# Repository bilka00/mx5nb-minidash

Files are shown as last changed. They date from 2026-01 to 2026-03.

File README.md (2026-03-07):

# Mazda MX-5 NB minidash
  Mini gauge display for Mazda MX-5 NB — oil pressure, temps, ECU data (Invent Labs, ME442). Replaces stock oil pressure gauge (or other 42mm gauge)
  Waveshare RP2350 + 1.43" AMOLED - https://www.waveshare.com/product/rp2350-touch-amoled-1.43.htm
  Preview:
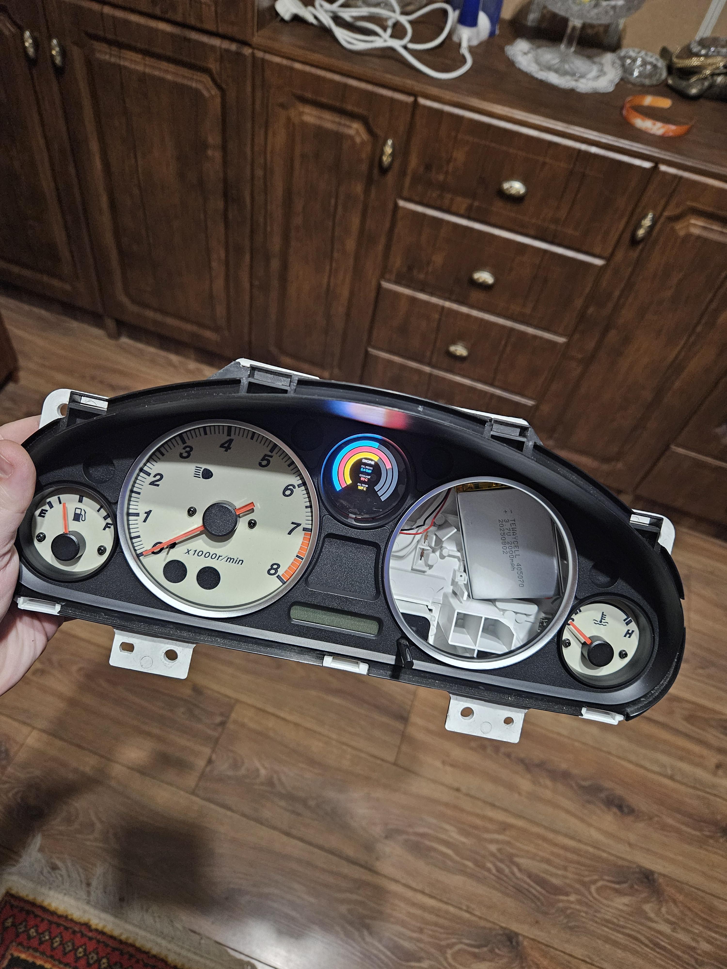
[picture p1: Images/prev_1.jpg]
First demo preview
  
## PCB
  Gerbers for pcb
  I received the boards from the factory and have already conducted the first tests. 
RS232 - works stably. The DC-DC ratings in the circuit are selected from those I have, you can choose better (resistors R7 R8).
  CAN bus works too!
  I haven't tested the ADC yet, I'm waiting for the components.
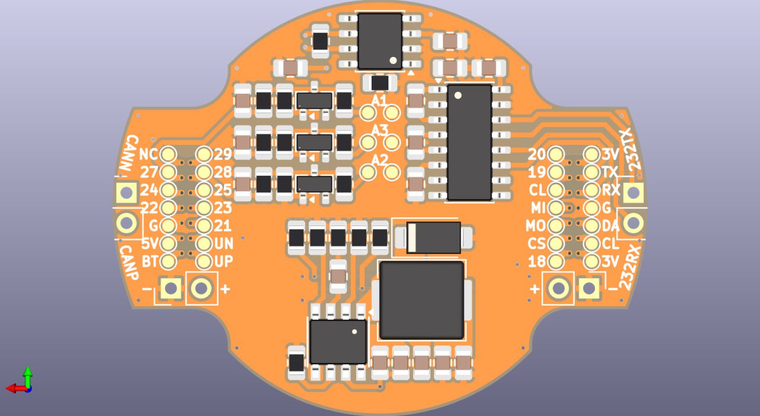
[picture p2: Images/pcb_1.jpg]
PCB_1
  
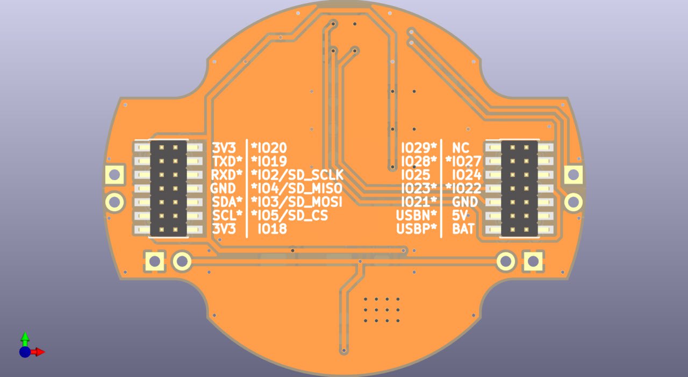
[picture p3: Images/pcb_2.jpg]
PCB_2
  
## Source 
  There are two projects there. One is an emulator, it can emulate both Invent and CAN ME442 (but that's not accurate, Claude). The second is the dashboard firmware itself, see config.h
## 3D Model
  3D models designed for 3D printing to mount the display to replace the factory gauge
## Demo
  Firmware source code for Demo application
## Invent Labs EMS (While this integration is not implemented)
  Firmware source code and scematic for EMS BUS intergate 
  
  Invent Labs EMS Bus is Inverted 12V UART (NOT RS232!!!, hotfix: 2k resistor - RS232 RX and VIN), speed 19200bps
  
  New board in progress. Let's abandon max2323 and make an inverter + logic level convertor on n-mos
  
## ME442 (While this integration is not implemented)
  Firmware source code and scematic for ME442 CAN intergate 
  
  ME442 CAN is CAN2.0b, variable speed, Command DB
## Images
  Image for readme

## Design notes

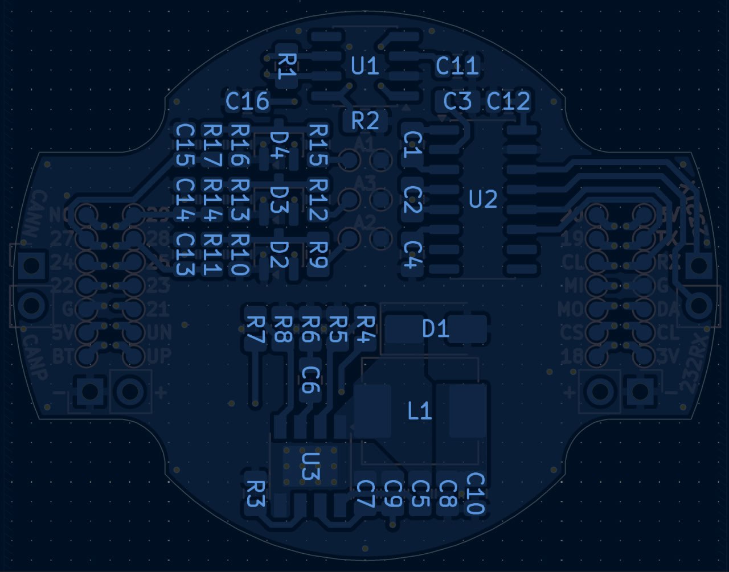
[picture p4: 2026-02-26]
PCB/footprint.jpg

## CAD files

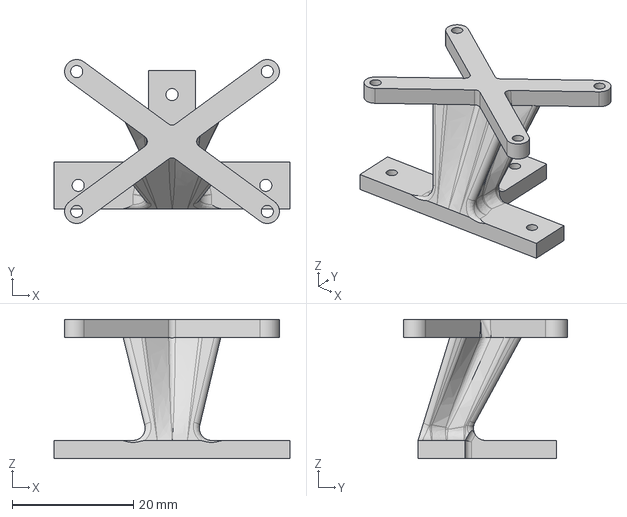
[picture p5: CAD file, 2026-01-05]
3D Model/MiataNB_DASH_OIL_REPLACE.step
39.0 x 27.1 x 23.0 mm

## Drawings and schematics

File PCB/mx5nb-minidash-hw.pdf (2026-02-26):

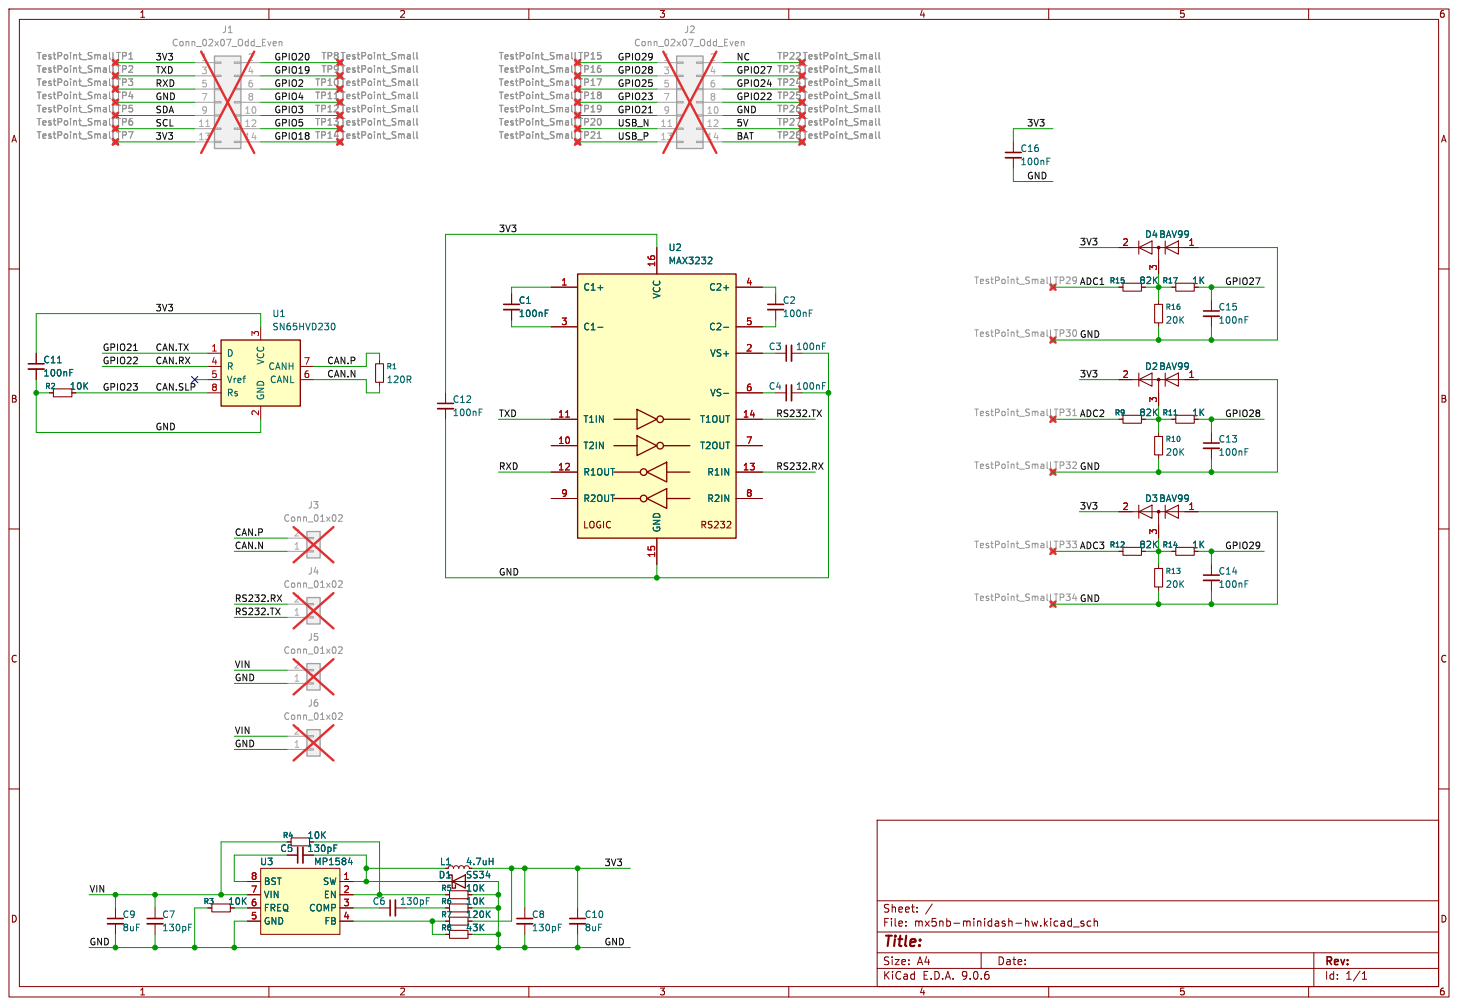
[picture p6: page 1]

2 CANH 7 CANL 6 U1SN65HVD230 RS232.RX GND GND

Id: 1/1 Title: File: mx5nb-minidash-hw.kicad_sch Sheet: /

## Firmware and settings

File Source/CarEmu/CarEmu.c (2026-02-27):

/*
 * Invent EMS Protocol TX Emulator
 * RP2040 (Pico SDK) — UART1 (GP4=TX, GP5=RX)
 *
 * Generates TInfoPacket with rotating slow packets
 * for testing the parser/receiver side.
 *
 * USB CDC serial used for debug/commands (printf).
 */

#include <stdio.h>
#include <string.h>
#include <stdlib.h>
#include <math.h>
#include <stdbool.h>

#include "pico/stdlib.h"
#include "pico/stdio_usb.h"
#include "hardware/uart.h"
#include "hardware/irq.h"
#include "hardware/clocks.h"
#include "can2040.h"

// ============================================================
// Type aliases
// ============================================================
typedef uint8_t  uint8;
typedef int8_t   int8;
typedef uint16_t uint16;
typedef int16_t  int16;

// ============================================================
// Protocol constants
// ============================================================
#define PROTOCOL_VERSION    0x54
#define SLOW_PACKET_SIZE    11
#define SLOW_PACKETS_COUNT  4
#define VERY_SLOW_PACKETS_COUNT 6
#define TOTAL_SLOW_PACKETS  (SLOW_PACKETS_COUNT + VERY_SLOW_PACKETS_COUNT) // 10

// Header: 0x55 0x00 0xAA 0x00 <version>
static const uint8_t HEADER[] = { 0x55, 0x00, 0xAA, 0x00, PROTOCOL_VERSION };
#define HEADER_SIZE 5

// UART1 pins & baud
#define UART_ID      uart1
#define UART_TX_PIN  4
#define UART_RX_PIN  5
#define UART_BAUD    19200

// CAN bus (PIO0, SN65HVD230 transceiver)
#define CAN_PIO_NUM    0
#define CAN_BITRATE    500000
#define CAN_GPIO_TX    21
#define CAN_GPIO_RX    22

// Packet send interval (ms)
#define TX_INTERVAL_MS 20  // ~50 Hz main packet rate

// ============================================================
// Packed structs (mirroring packet_info.h)
// ============================================================
#pragma pack(push, 1)

// --- Flag unions ---

typedef union {
    uint8 All;
    struct {
        uint8 DPKV     : 1,
              DF       : 1,
              DBW      : 1,
              DAD      : 1,
              DNO      : 1,
              CLT      : 1,
              OILP     : 1,
              FUELP    : 1;
    };
} TFlagMajor;

typedef union {
    uint8 All;
    struct {
        uint8 Lambda : 1,
              IAT    : 1,
              FuelT  : 1,
              OilT   : 1,
              VVT    : 1,
              EGR    : 1;
    };
} TFlagMinor;

typedef union {
    uint8 All;
    struct {
        uint8 TableSwitch      : 1,
              InjTimeLimit     : 1,
              Marker           : 1,
              AfterStartEnrich : 1,
              PhasedMode       : 1,
              WritePending     : 1,
              Methanol         : 1,
              IdleCutoff       : 1;
    };
} TFlagNotify;

typedef union {
    uint8 All;
    struct {
        uint8 Launch    : 1,
              FlatShift : 1,
              AntiLag   : 1;
    };
} TFlagNotify2;

typedef union {
    uint8 All;
    struct {
        uint8 Rpm       : 1,
              Overboost : 1,
              Lambda    : 1,
              InjDuty   : 1,
              Clt       : 1,
              Egt       : 1,
              OilT      : 1;
    };
} TFlagProtection;

typedef union {
    uint8 All;
    struct {
        uint8 PartLock  : 1,
              FullLock  : 1,
              Shifting  : 1,
              Retard    : 1,
              __free    : 1,
              Selector  : 3;
    };
} TATState;

// --- Slow packet structs (all padded to SLOW_PACKET_SIZE = 11 bytes) ---

typedef struct {
    int8   CorrAngle;
    uint8  LambdaTarget;
    int8   LambdaCorrFast;
    int8   LambdaCorrSlow;
    uint16 FuelPKpa;
    uint8  DwellTime;
    uint8  Voltage;
    int8   GearNo;
    uint8  DbwCommandedPos;
    uint8  Lambda2;
} TInfoPacketSlow0;

typedef struct {
    TFlagMajor      FlagMajor;
    TFlagMinor      FlagMinor;
    TFlagNotify     FlagNotify;
    TFlagNotify2    FlagNotify2;
    TFlagProtection FlagProtection;
    uint8  IdlePos;
    uint16 Airflow;
    uint8  BoostDuty;
    uint8  BoostTarget;
    uint8  _free;
} TInfoPacketSlow1;

typedef struct {
    uint8  EgrCurrentPos;
    uint8  EgrTargetPos;
    uint8  InjDutyCycle;
    int16  InjLagTime;
    int8   InjEndAngle4;
    uint8  FuelPressureCoef;
    int8   AirChargeT;
    int8   InjAirChargeCorr;
    uint8  Speed2;
    uint8  BackPKpa;
} TInfoPacketSlow2;

typedef struct {
    int16  IgnAccelCorrDelta;
    int8   Vvt1CurrAngle;
    int8   Vvt1TargetAngle;
    int8   Vvt2CurrAngle;
    int8   Vvt2TargetAngle;
    int8   Vvt1bCurrAngle;
    int8   Vvt2bCurrAngle;
    uint8  TcsCorr;
    uint8  Pwm3DTarget;
    uint8  Pwm3DCurr;
} TInfoPacketSlow3;

typedef struct {
    uint16 TripFuel;
    uint16 TripPath;
    uint16 CurrFuelCons;
    uint16 TripFuelCons;
    uint8  FuelComposition;
    uint8  free2;
    uint8  _free;
} TInfoPacketSlow4;

typedef struct {
    uint8  AdcTps;
    uint8  AdcCt;
    uint8  AdcIat;
    uint8  DbwAdc1;
    uint8  DbwAdc2;
    uint8  AdcMap;
    uint8  AdcLambda;
    uint8  SlotNo;
    uint8  SlotLatency;
    uint8  SlotTime;
    uint8  _free;
} TInfoPacketSlow5;

typedef struct {
    uint8  AdcAn1;
    uint8  AdcAn2;
    uint8  AdcAn3;
    uint8  AdcAn4;
    uint8  AdcAn5;
    uint8  AdcAn6;
    uint8  AdcAn7;
    uint8  AdcAn8;
    uint8  AdcAn9;
    uint8  AdcAn10;
    uint8  _free;
} TInfoPacketSlow6;

typedef struct {
    uint8  InputState;
    uint16 OutputState;
    uint8  DbwDriverStatus;
    uint8  DbwSystemStatus;
    uint8  GasState;
    int8   ATTemp;
    uint8  ATState;
    uint8  FuelLevel;
    uint8  padding4;
    uint8  _free;
} TInfoPacketSlow7;

typedef struct {
    int8   Clt;
    int8   Iat;
    uint8  OilT;
    int8   FuelT;
    uint8  _free;
    uint16 Egt1;
    uint16 Egt2;
    uint8  OilP;
    uint8  _free2;
} TInfoPacketSlow8;

typedef struct {
    uint8  Pwm1Duty;
    uint8  Pwm2Duty;
    uint8  Pwm3Duty;
    uint8  Pwm4Duty;
    uint8  Pwm5Duty;
    uint8  Pwm6Duty;
    uint8  _free;
    uint8  _free2;
    uint8  _free3;
    uint8  _free4;
    uint8  _free5;
} TInfoPacketSlow9;

// Slow packet union
typedef union {
    TInfoPacketSlow0 Pkt0;
    TInfoPacketSlow1 Pkt1;
    TInfoPacketSlow2 Pkt2;
    TInfoPacketSlow3 Pkt3;
    TInfoPacketSlow4 Pkt4;
    TInfoPacketSlow5 Pkt5;
    TInfoPacketSlow6 Pkt6;
    TInfoPacketSlow7 Pkt7;
    TInfoPacketSlow8 Pkt8;
    TInfoPacketSlow9 Pkt9;
    uint8 raw[SLOW_PACKET_SIZE];
} TSlowPacket;

// Main info packet
typedef struct {
    uint8       Length;
    uint8       Type;
    uint8       Runlevel;
    int16       Uoz;
    uint8       Rashod;
    uint16      Period;
    uint16      InjTime;
    uint8       KnockVoltage;
    uint8       Tps;
    uint8       DbwCurrPos;
    uint8       MapKpa;
    uint8       Lambda;
    uint8       CylNo;
    int8        TransientCorr;
    uint8       Speed;
    uint8       KnockVoltagePerCyl;
    uint8       KnockRetardPerCyl;
    int8        TmrDifPerCyl;
    uint8       Debug1;
    int16       Debug2;
    uint8       SlowPacketId;
    TSlowPacket SlowPacket;
} TInfoPacket;

#pragma pack(pop)

// Compile-time struct size checks
_Static_assert(sizeof(TInfoPacketSlow0) == SLOW_PACKET_SIZE, "Slow0 size mismatch");
_Static_assert(sizeof(TInfoPacketSlow1) == SLOW_PACKET_SIZE, "Slow1 size mismatch");
_Static_assert(sizeof(TInfoPacketSlow2) == SLOW_PACKET_SIZE, "Slow2 size mismatch");
_Static_assert(sizeof(TInfoPacketSlow3) == SLOW_PACKET_SIZE, "Slow3 size mismatch");
_Static_assert(sizeof(TInfoPacketSlow4) == SLOW_PACKET_SIZE, "Slow4 size mismatch");
_Static_assert(sizeof(TInfoPacketSlow5) == SLOW_PACKET_SIZE, "Slow5 size mismatch");
_Static_assert(sizeof(TInfoPacketSlow6) == SLOW_PACKET_SIZE, "Slow6 size mismatch");
_Static_assert(sizeof(TInfoPacketSlow7) == SLOW_PACKET_SIZE, "Slow7 size mismatch");
_Static_assert(sizeof(TInfoPacketSlow8) == SLOW_PACKET_SIZE, "Slow8 size mismatch");
_Static_assert(sizeof(TInfoPacketSlow9) == SLOW_PACKET_SIZE, "Slow9 size mismatch");
_Static_assert(sizeof(TSlowPacket)      == SLOW_PACKET_SIZE, "SlowPacket union size mismatch");

// ============================================================
// CRC-16 (matches the receiver's Checksum function exactly)
// ============================================================
static uint16_t calcChecksum(const uint8_t* buffer)
{
    uint8_t len = buffer[0] - 2;
    uint16_t crc = 0xFFFF;

    for (uint8_t i = 0; i <= len; i++)
    {
        uint8_t data = buffer[i];
        data ^= crc & 0xFF;
        data ^= data << 4;
        uint16_t t = ((uint16_t)data << 8) | ((crc >> 8) & 0xFF);
        t ^= (uint8_t)(data >> 4);
        t ^= (uint16_t)data << 3;
        crc = t;
    }
    return crc;
}

// ============================================================
// Simulated engine state
// ============================================================
typedef struct {
    // Fast channels
    float   rpm;
    float   angleDeg;
    float   tpsPercent;
    float   dbwPercent;
    float   mapKpa;
    float   lambdaVal;
    float   injTimeMs;
    float   rashodLH;
    uint8_t knockV;
    uint8_t cylNo;
    int8_t  transCorr;
    uint8_t speed;
    uint8_t runlevel;

    // Slow0
    int8_t   corrAngle;
    float    lambdaTarget;
    int8_t   lambdaCorrFast;
    int8_t   lambdaCorrSlow;
    uint16_t fuelPKpa;
    uint8_t  dwellTime;
    float    voltageV;
    int8_t   gearNo;
    uint8_t  dbwCmdPos;
    float    lambda2Val;

    // Slow1
    uint8_t  flagMajor;
    uint8_t  flagMinor;
    uint8_t  flagNotify;
    uint8_t  flagNotify2;
    uint8_t  flagProtection;
    float    idlePosPercent;
    uint16_t airflow;
    uint8_t  boostDuty;
    uint8_t  boostTarget;

    // Slow2
    uint8_t  egrCurrPos;
    uint8_t  egrTargetPos;
    uint8_t  injDutyCycle;
    int16_t  injLagTime;
    int8_t   injEndAngle4;
    uint8_t  fuelPressCoef;
    int8_t   airChargeT;
    int8_t   injAirChargeCorr;
    uint8_t  speed2;
    float    backPKpa;

    // Slow3
    int16_t  ignAccelCorr;
    int8_t   vvt1Curr;
    int8_t   vvt1Target;
    int8_t   vvt2Curr;
    int8_t   vvt2Target;
    int8_t   vvt1bCurr;
    int8_t   vvt2bCurr;
    uint8_t  tcsCorr;
    float    pwm3dTarget;
    float    pwm3dCurr;

    // Slow4
    float    tripFuelL;
    float    tripPathKm;
    float    currFuelCons;
    float    tripFuelCons;
    float    fuelCompPct;

    // Slow5
    float    adcTpsV;
    float    adcCtV;
    float    adcIatV;
    float    dbwAdc1V;
    float    dbwAdc2V;
    float    adcMapV;
    float    adcLambdaV;

    // Slow6
    float    adcAn[10];

    // Slow7
    uint8_t  inputState;
    uint16_t outputState;
    uint8_t  dbwDriverStatus;
    uint8_t  dbwSystemStatus;
    uint8_t  gasState;
    int8_t   atTemp;
    uint8_t  atState;
    uint8_t  fuelLevel;

    // Slow8
    int8_t   clt;
    int8_t   iat;
    uint8_t  oilT;
    int8_t   fuelT;
    uint16_t egt1;
    uint16_t egt2;
    float    oilPBar;

    // Manual override flags (skip simulation when set via serial)
    bool     cltOverride;
    bool     oilTOverride;
    bool     oilPOverride;

    // Slow9
    float    pwmDuty[6];

    // CAN DBC extra fields
    float    afrTarget;
    uint16_t rpmHardLimit;
    uint16_t knockEvsCnt;
    float    mapTargetKpa;
} EngineState;

static EngineState eng;

static void initEngineState(void)
{
    memset(&eng, 0, sizeof(eng));

    // Fast channels
    eng.rpm        = 850.0f;
    eng.angleDeg   = 10.0f;
    eng.tpsPercent = 5.0f;
    eng.dbwPercent = 5.0f;
    eng.mapKpa     = 35.0f;
    eng.lambdaVal  = 1.0f;
    eng.injTimeMs  = 2.5f;
    eng.rashodLH   = 1.5f;
    eng.knockV     = 10;
    eng.runlevel   = 2;

    // Slow0
    eng.corrAngle      = -2;
    eng.lambdaTarget   = 1.0f;
    eng.lambdaCorrFast = 3;
    eng.lambdaCorrSlow = -1;
    eng.fuelPKpa       = 300;
    eng.dwellTime      = 35;
    eng.voltageV       = 14.1f;
    eng.dbwCmdPos      = 12;
    eng.lambda2Val     = 1.02f;

    // Slow1
    eng.flagNotify     = 0x10; // PhasedMode
    eng.idlePosPercent = 30.0f;
    eng.airflow        = 120;
    eng.boostTarget    = 50;

    // Slow2
    eng.injDutyCycle   = 15;
    eng.injLagTime     = 120;
    eng.injEndAngle4   = -20;
    eng.fuelPressCoef  = 100;
    eng.airChargeT     = 25;
    eng.backPKpa       = 101.0f;

    // Slow3
    eng.vvt1Curr       = 5;
    eng.vvt1Target     = 10;

    // Slow4
    eng.tripFuelL      = 3.25f;
    eng.tripPathKm     = 42.5f;
    eng.currFuelCons   = 7.6f;
    eng.tripFuelCons   = 7.6f;

    // Slow5
    eng.adcTpsV    = 0.8f;
    eng.adcCtV     = 2.1f;
    eng.adcIatV    = 2.5f;
    eng.dbwAdc1V   = 0.8f;
    eng.dbwAdc2V   = 3.2f;
    eng.adcMapV    = 1.0f;
    eng.adcLambdaV = 0.45f;

    // Slow6
    for (int i = 0; i < 10; i++)
        eng.adcAn[i] = 1.0f;

    // Slow7
    eng.atTemp    = 60;
    eng.fuelLevel = 128;

    // Slow8
    eng.clt    = 85;
    eng.iat    = 30;
    eng.oilT   = 95;
    eng.fuelT  = 35;
    eng.egt1   = 650;
    eng.egt2   = 640;
    eng.oilPBar = 3.5f;

    // Slow9
    eng.pwmDuty[0] = 50.0f;

    // CAN DBC extra
    eng.afrTarget    = 14.7f;
    eng.rpmHardLimit = 8000;
    eng.knockEvsCnt  = 0;
    eng.mapTargetKpa = 100.0f;
}

// ============================================================
// Helpers
// ============================================================

static uint16_t rpmToPeriod(float rpm)
{
    if (rpm <= 0) return 0;
    uint32_t p = (uint32_t)(10000000.0f / rpm);
    return (p > 65535) ? 65535 : (uint16_t)p;
}

static uint8_t clampU8(float v)
{
    if (v < 0) return 0;
    if (v > 255) return 255;
    return (uint8_t)(v + 0.5f);
}

// ============================================================
// Fill slow packets
// ============================================================

static void fillSlow0(TInfoPacketSlow0* p)
{
    p->CorrAngle      = eng.corrAngle;
    p->LambdaTarget   = clampU8(eng.lambdaTarget * 128.0f);
    p->LambdaCorrFast = eng.lambdaCorrFast;
    p->LambdaCorrSlow = eng.lambdaCorrSlow;
    p->FuelPKpa       = eng.fuelPKpa;
    p->DwellTime      = eng.dwellTime;
    p->Voltage        = clampU8(eng.voltageV / 0.1f);
    p->GearNo         = eng.gearNo;
    p->DbwCommandedPos = eng.dbwCmdPos;
    p->Lambda2        = clampU8(eng.lambda2Val * 128.0f);
}

static void fillSlow1(TInfoPacketSlow1* p)
{
    p->FlagMajor.All      = eng.flagMajor;
    p->FlagMinor.All      = eng.flagMinor;
    p->FlagNotify.All     = eng.flagNotify;
    p->FlagNotify2.All    = eng.flagNotify2;
    p->FlagProtection.All = eng.flagProtection;
    p->IdlePos            = clampU8(eng.idlePosPercent * 256.0f / 100.0f);
    p->Airflow            = eng.airflow;
    p->BoostDuty          = eng.boostDuty;
    p->BoostTarget        = eng.boostTarget;
    p->_free              = 0;
}

static void fillSlow2(TInfoPacketSlow2* p)
{
    p->EgrCurrentPos    = eng.egrCurrPos;
    p->EgrTargetPos     = eng.egrTargetPos;
    p->InjDutyCycle     = eng.injDutyCycle;
    p->InjLagTime       = eng.injLagTime;
    p->InjEndAngle4     = eng.injEndAngle4;
    p->FuelPressureCoef = eng.fuelPressCoef;
    p->AirChargeT       = eng.airChargeT;
    p->InjAirChargeCorr = eng.injAirChargeCorr;
    p->Speed2           = eng.speed2;
    p->BackPKpa         = clampU8(eng.backPKpa / 2.0f);
}

static void fillSlow3(TInfoPacketSlow3* p)
{
    p->IgnAccelCorrDelta = eng.ignAccelCorr;
    p->Vvt1CurrAngle    = eng.vvt1Curr;
    p->Vvt1TargetAngle  = eng.vvt1Target;
    p->Vvt2CurrAngle    = eng.vvt2Curr;
    p->Vvt2TargetAngle  = eng.vvt2Target;
    p->Vvt1bCurrAngle   = eng.vvt1bCurr;
    p->Vvt2bCurrAngle   = eng.vvt2bCurr;
    p->TcsCorr          = eng.tcsCorr;
    p->Pwm3DTarget      = clampU8(eng.pwm3dTarget * 256.0f / 100.0f);
    p->Pwm3DCurr        = clampU8(eng.pwm3dCurr * 256.0f / 100.0f);
}

static void fillSlow4(TInfoPacketSlow4* p)
{
    p->TripFuel        = (uint16_t)(eng.tripFuelL / 0.01f);
    p->TripPath        = (uint16_t)(eng.tripPathKm / 0.1f);
    p->CurrFuelCons    = (uint16_t)(eng.currFuelCons / 0.1f);
    p->TripFuelCons    = (uint16_t)(eng.tripFuelCons / 0.1f);
    p->FuelComposition = clampU8(eng.fuelCompPct * 256.0f / 100.0f);
    p->free2           = 0;
    p->_free           = 0;
}

static void fillSlow5(TInfoPacketSlow5* p)
{
    p->AdcTps    = clampU8(eng.adcTpsV * 256.0f / 5.0f);
    p->AdcCt     = clampU8(eng.adcCtV * 256.0f / 5.0f);
    p->AdcIat    = clampU8(eng.adcIatV * 256.0f / 5.0f);
    p->DbwAdc1   = clampU8(eng.dbwAdc1V * 256.0f / 5.0f);
    p->DbwAdc2   = clampU8(eng.dbwAdc2V * 256.0f / 5.0f);
    p->AdcMap    = clampU8(eng.adcMapV * 256.0f / 5.0f);
    p->AdcLambda = clampU8(eng.adcLambdaV * 256.0f / 5.0f);
    p->SlotNo      = 0;
    p->SlotLatency = 0;
    p->SlotTime    = 0;
    p->_free       = 0;
}

static void fillSlow6(TInfoPacketSlow6* p)
{
    uint8_t* an = &p->AdcAn1;
    for (int i = 0; i < 10; i++)
        an[i] = clampU8(eng.adcAn[i] * 256.0f / 5.0f);
    p->_free = 0;
}

static void fillSlow7(TInfoPacketSlow7* p)
{
    p->InputState       = eng.inputState;
    p->OutputState      = eng.outputState;
    p->DbwDriverStatus  = eng.dbwDriverStatus;
    p->DbwSystemStatus  = eng.dbwSystemStatus;
    p->GasState         = eng.gasState;
    p->ATTemp           = eng.atTemp;
    p->ATState          = eng.atState;
    p->FuelLevel        = eng.fuelLevel;
    p->padding4         = 0;
    p->_free            = 0;
}

static void fillSlow8(TInfoPacketSlow8* p)
{
    p->Clt    = eng.clt;
    p->Iat    = eng.iat;
    p->OilT   = eng.oilT;
    p->FuelT  = eng.fuelT;
    p->_free  = 0;
    p->Egt1   = eng.egt1;
    p->Egt2   = eng.egt2;
    p->OilP   = clampU8(eng.oilPBar / 0.1f);
    p->_free2 = 0;
}

static void fillSlow9(TInfoPacketSlow9* p)
{
    p->Pwm1Duty = clampU8(eng.pwmDuty[0] * 256.0f / 100.0f);
    p->Pwm2Duty = clampU8(eng.pwmDuty[1] * 256.0f / 100.0f);
    p->Pwm3Duty = clampU8(eng.pwmDuty[2] * 256.0f / 100.0f);
    p->Pwm4Duty = clampU8(eng.pwmDuty[3] * 256.0f / 100.0f);
    p->Pwm5Duty = clampU8(eng.pwmDuty[4] * 256.0f / 100.0f);
    p->Pwm6Duty = clampU8(eng.pwmDuty[5] * 256.0f / 100.0f);
    p->_free  = 0;
    p->_free2 = 0;
    p->_free3 = 0;
    p->_free4 = 0;
    p->_free5 = 0;
}

// ============================================================
// Build and send one complete packet
// ============================================================

static uint8_t txbuf[sizeof(TInfoPacket) + 2];
static uint8_t slowPacketIndex = 0;
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
int main(void)
{
    // Init USB stdio
    stdio_init_all();

    // Init UART1
    uart_init(UART_ID, UART_BAUD);
    gpio_set_function(UART_TX_PIN, GPIO_FUNC_UART);
    gpio_set_function(UART_RX_PIN, GPIO_FUNC_UART);

    // Init engine state
    initEngineState();

    // CAN bus starts disabled — type 'canstart' when bus is ready.
    // Keep TX pin HIGH (recessive) so the SN65HVD230 doesn't drive
    // the bus dominant while CAN is not yet initialised.
    gpio_init(CAN_GPIO_TX);
    gpio_set_dir(CAN_GPIO_TX, GPIO_OUT);
    gpio_put(CAN_GPIO_TX, 1);

    // Wait for USB CDC connection before printing
    while (!stdio_usb_connected())
        sleep_ms(100);

    printf("=== Invent EMS Protocol TX Emulator ===\n");
    printf("sizeof(TInfoPacket) = %d\n", (int)sizeof(TInfoPacket));
    printf("Packet on wire: %d bytes (header %d + payload %d + CRC 2)\n",
           (int)(HEADER_SIZE + sizeof(TInfoPacket) + 2),
           HEADER_SIZE, (int)sizeof(TInfoPacket));
    printf("UART1: TX=GP%d  RX=GP%d  %d baud\n", UART_TX_PIN, UART_RX_PIN, UART_BAUD);
    printf("CAN:   TX=GP%d  RX=GP%d  %d kbps (PIO%d) — type 'canstart' to enable\n",
           CAN_GPIO_TX, CAN_GPIO_RX, CAN_BITRATE / 1000, CAN_PIO_NUM);
    printf("Type 'help' for commands.\n");

    uint32_t lastTx = to_ms_since_boot(get_absolute_time());

    while (true) {
        uint32_t now = to_ms_since_boot(get_absolute_time());

        if (now - lastTx >= TX_INTERVAL_MS) {
            float dt = (now - lastTx) / 1000.0f;
            lastTx = now;

            simulateEngine(dt);
            buildAndSend();
            sendAllCAN();
        }

        processSerialCommands();
    }

    return 0;
}

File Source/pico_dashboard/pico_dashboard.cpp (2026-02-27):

/**
 * pico_dashboard — main entry point
 *
 * Core 0: LVGL rendering, display flush (PIO2 QSPI DMA), touch input.
 * Core 1: CAN bus reception + protocol parsing (PIO0, ME442 mode only).
 *
 * ECU data flows:  core 1 → invent_ems_data_t → core 0 LVGL timer → UI.
 * All LVGL widget updates happen inside lv_timer_handler() to respect
 * LVGL's single-threaded dirty-area tracking.
 *
 * SPDX-License-Identifier: BSD-3-Clause
 */

#include <stdio.h>
#include "pico/stdlib.h"
#include "hardware/clocks.h"
#include "hardware/structs/sio.h"

#include "config.h"
#include "lv_port_disp.h"
#include "lv_port_indev.h"
#include "bsp_i2c.h"
#include "ui/ui_dashboard.h"
#include "ui/ui_debug_console.h"

extern "C" {
#include "bsp_serial.h"
#include "bsp_can.h"
#include "protocol/invent_ems.h"
}

#if ECU_PROTOCOL == ECU_ME442
#include "pico/multicore.h"
#endif

/* ---- Clock configuration ---- */

static void set_cpu_clock(uint32_t freq_mhz)
{
    set_sys_clock_hz(freq_mhz * MHZ, true);
    /* Re-derive peripheral clock from the new PLL frequency so that
     * UART / SPI baud rates remain correct after the speed change. */
    clock_configure(clk_peri, 0,
                    CLOCKS_CLK_PERI_CTRL_AUXSRC_VALUE_CLKSRC_PLL_SYS,
                    freq_mhz * MHZ, freq_mhz * MHZ);
}

/* ---- LVGL tick (1 ms hardware timer ISR) ---- */

static bool repeating_lvgl_timer_cb(struct repeating_timer *t)
{
    (void)t;
    lv_tick_inc(LVGL_TICK_PERIOD_MS);
    return true;
}

/* ======================================================================
 * ECU_INVENT_EMS — UART path (core 0 only)
 * ====================================================================== */
#if ECU_PROTOCOL == ECU_INVENT_EMS

/*
 * UART0 RX interrupt ring buffer.
 * At 19200 baud packets arrive every ~22 ms, but lv_timer_handler() can
 * block for 20-50 ms during rendering.  The hardware FIFO is only 32 B
 * (~16.7 ms at 19200), so without an ISR we lose bytes and get CRC errors.
 */
#define UART_RX_BUF_SIZE 256
static volatile uint8_t  uart_rx_buf[UART_RX_BUF_SIZE];
static volatile uint16_t uart_rx_head = 0;
static uint16_t          uart_rx_tail = 0;

extern "C" void uart0_irq_handler(void)
{
    while (uart_is_readable(uart0)) {
        uint8_t ch = (uint8_t)uart_getc(uart0);
        uint16_t next = (uart_rx_head + 1) % UART_RX_BUF_SIZE;
        if (next != uart_rx_tail) {           /* drop on overflow */
            uart_rx_buf[uart_rx_head] = ch;
            uart_rx_head = next;
        }
    }
}

#endif /* ECU_INVENT_EMS */

/* ======================================================================
 * ECU_ME442 — CAN path (core 1 drains CAN + parses, core 0 just reads)
 * ====================================================================== */
#if ECU_PROTOCOL == ECU_ME442

static void core1_entry(void)
{
    bsp_can_init();     /* PIO0 IRQ is registered on core 1 NVIC */

    bsp_can_frame_t frame;
    while (true) {
        while (bsp_can_recv(&frame))
            invent_ems_feed_can_frame(frame.id, frame.data, frame.dlc);
        tight_loop_contents();
    }
}

#endif /* ECU_ME442 */

/* ======================================================================
 * LVGL timer callbacks (run inside lv_timer_handler on core 0)
 * ====================================================================== */

/* Flag set by main loop when the protocol parser signals new data.
 * The LVGL timer reads it so that widget updates stay inside the
 * lv_timer_handler() context (required for correct dirty-area tracking). */
static volatile bool ecu_data_ready = false;

static void dashboard_update_cb(lv_timer_t *timer)
{
    (void)timer;
    if (!ecu_data_ready) return;
    ecu_data_ready = false;

    const invent_ems_data_t *ecu = invent_ems_get_data();
    ui_dashboard_set_oil_pressure(ecu->oil_pressure);
    ui_dashboard_set_coolant_temp(ecu->clt);
    ui_dashboard_set_oil_temp(ecu->oil_temp);
}

#if ENABLE_DEBUG_CONSOLE
static void debug_stats_cb(lv_timer_t *timer)
{
    (void)timer;
    const invent_ems_data_t *ecu = invent_ems_get_data();

    bsp_can_stats_t can = {0};
#if ECU_PROTOCOL == ECU_ME442
    can = bsp_can_get_stats();
    can.rx_pin_raw = (sio_hw->gpio_in & (1u << BSP_CAN_GPIO_RX)) ? 1 : 0;
#endif

    ui_debug_console_update_stats(
        ecu->packet_count, ecu->error_count, ecu->connected, &can);
}
#endif /* ENABLE_DEBUG_CONSOLE */

/* ======================================================================
 * main
 * ====================================================================== */

int main()
{
    stdio_init_all();
    set_cpu_clock(CPU_CLOCK_MHZ);
    bsp_i2c_init();

    /* ---- LVGL init ---- */
    lv_init();
    lv_port_disp_init(DISP_HOR_RES, DISP_VER_RES, 0, false);
    lv_port_indev_init(DISP_HOR_RES, DISP_VER_RES, 0);

    static struct repeating_timer lvgl_timer;
    add_repeating_timer_ms(LVGL_TICK_PERIOD_MS,
                           repeating_lvgl_timer_cb, NULL, &lvgl_timer);

    /* ---- Protocol init ---- */
    invent_ems_init();

#if ECU_PROTOCOL == ECU_INVENT_EMS
    bsp_serial_init();
    uart_set_baudrate(uart0, INVENT_EMS_BAUD_RATE);
    irq_set_exclusive_handler(UART0_IRQ, uart0_irq_handler);
    irq_set_enabled(UART0_IRQ, true);
    uart_set_irqs_enabled(uart0, true, false);
#elif ECU_PROTOCOL == ECU_ME442
    multicore_launch_core1(core1_entry);
#endif

    /* ---- UI init ---- */
    ui_dashboard_init();
    ui_debug_console_init();

    lv_timer_create(dashboard_update_cb, DASHBOARD_UPDATE_MS, NULL);
#if ENABLE_DEBUG_CONSOLE
    lv_timer_create(debug_stats_cb, DEBUG_STATS_UPDATE_MS, NULL);
#endif

    /* ---- Super-loop ---- */
    uint16_t sleep_ms_val = LVGL_TICK_PERIOD_MS;

    while (true) {
#if ECU_PROTOCOL == ECU_INVENT_EMS
        /* Drain UART ring buffer → byte-level protocol parser */
        uint16_t head = uart_rx_head;
        while (uart_rx_tail != head) {
            uint8_t byte = uart_rx_buf[uart_rx_tail];
            uart_rx_tail = (uart_rx_tail + 1) % UART_RX_BUF_SIZE;
            invent_ems_feed_byte(byte);
        }
#endif
        /* Propagate "new ECU data" flag for the next LVGL timer tick */
        if (invent_ems_has_new_data())
            ecu_data_ready = true;

        sleep_ms_val = lv_timer_handler();
        if (sleep_ms_val > 500)             sleep_ms_val = 500;
        if (sleep_ms_val < LVGL_TICK_PERIOD_MS) sleep_ms_val = LVGL_TICK_PERIOD_MS;
        sleep_ms(sleep_ms_val);
    }
}

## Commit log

2026-01-20 Add pcb gerbers
2026-02-26 Add schematic
